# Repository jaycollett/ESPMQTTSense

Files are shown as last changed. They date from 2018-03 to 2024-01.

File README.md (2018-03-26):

# ESPMQTTSense
ESP8266 based environment sensor using the BME280 and MQTT communication. Designed to populate sensor data in my HASS.IO system. More details can be found in my blog post about this project [here](https://www.jaycollett.com/2018/03/cheap-environment-sensing-with-esp8266-mqtt).

**BOM**
----------
1. [ESP8266 ESP-01](https://www.aliexpress.com/item/WiFi-module-ESP8266-Serial-to-WiFi-wireless-transparent-transmission-industrial-ESP-01S/32716268094.html)
2. [Custom OSH Park PCBs x 3](https://oshpark.com/shared_projects/DTD2a0g7)
3. Passive Components - micro usb is part number: 10103594-0001LF
4. [Enclosure x5](https://www.ebay.com/itm/H1-5pcs-Plastic-Electric-Project-Junction-Box-60x36x25mm/282124733873)
5. [BME280 Sensor Module](https://www.banggood.com/CJMCU-280E-BME280-High-Precision-Atmospheric-Pressure-Sensor-For-Arduino-p-1103115.html)
6. [USB Wall Plug](https://www.aliexpress.com/item/Universal-USB-Charger-US-EU-Plug-5V-1A-Charger-Adapter-for-iphone-6-6s-7-7s/32822757190.html)
7. [1m USB Micro Cable](https://www.aliexpress.com/item/USB-Cable-Micro-USB-Cable-Charging-Sync-Data-Mobile-Phone-Cables-For-Android-Samsung-Xiaomi-Huawei/32852902325.html)



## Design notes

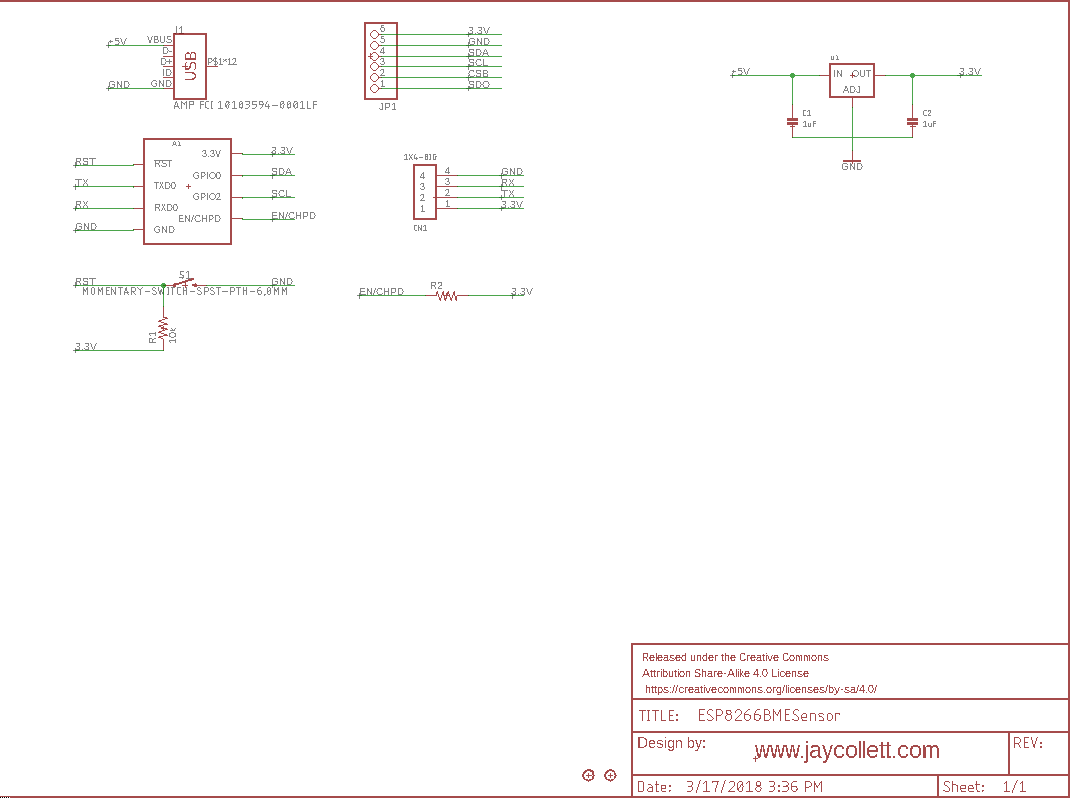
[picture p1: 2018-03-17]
EagleCAD/ESPMQTTSenseSchematic_NON_FTDI.png

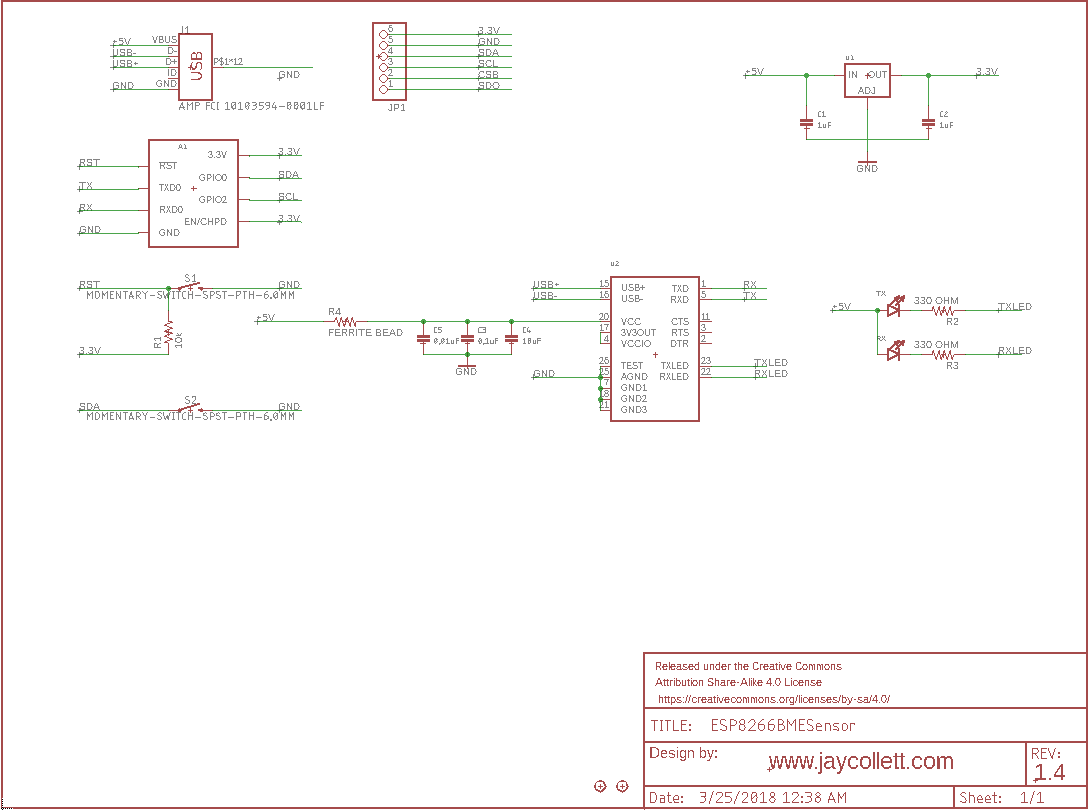
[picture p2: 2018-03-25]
EagleCAD/ESPMQTTSenseSchematic.PNG

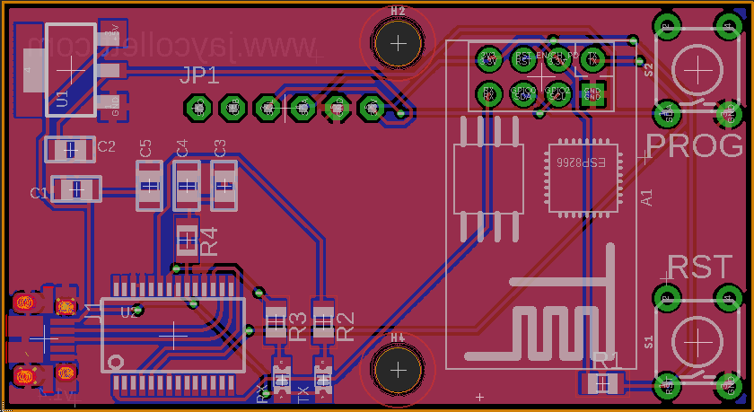
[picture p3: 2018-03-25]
EagleCAD/ESPMQTTSenseBoard.PNG

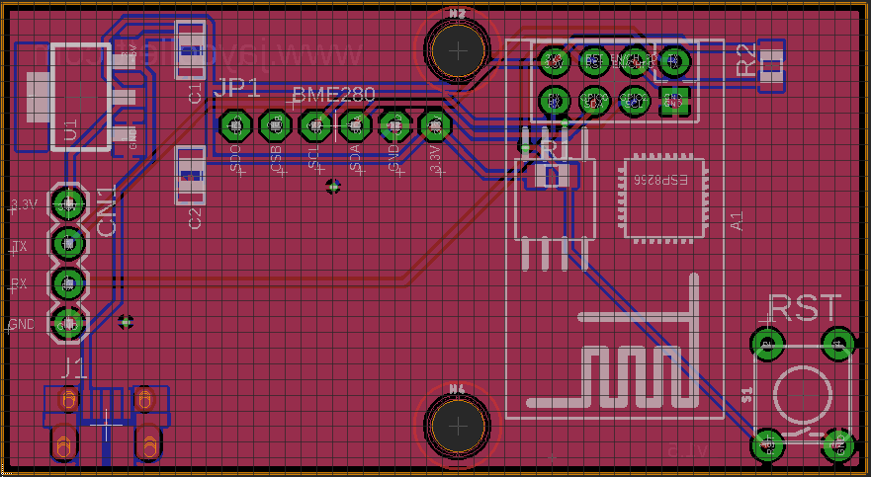
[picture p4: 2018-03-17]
EagleCAD/ESPMQTTSenseBoard_NON_FTDI.png

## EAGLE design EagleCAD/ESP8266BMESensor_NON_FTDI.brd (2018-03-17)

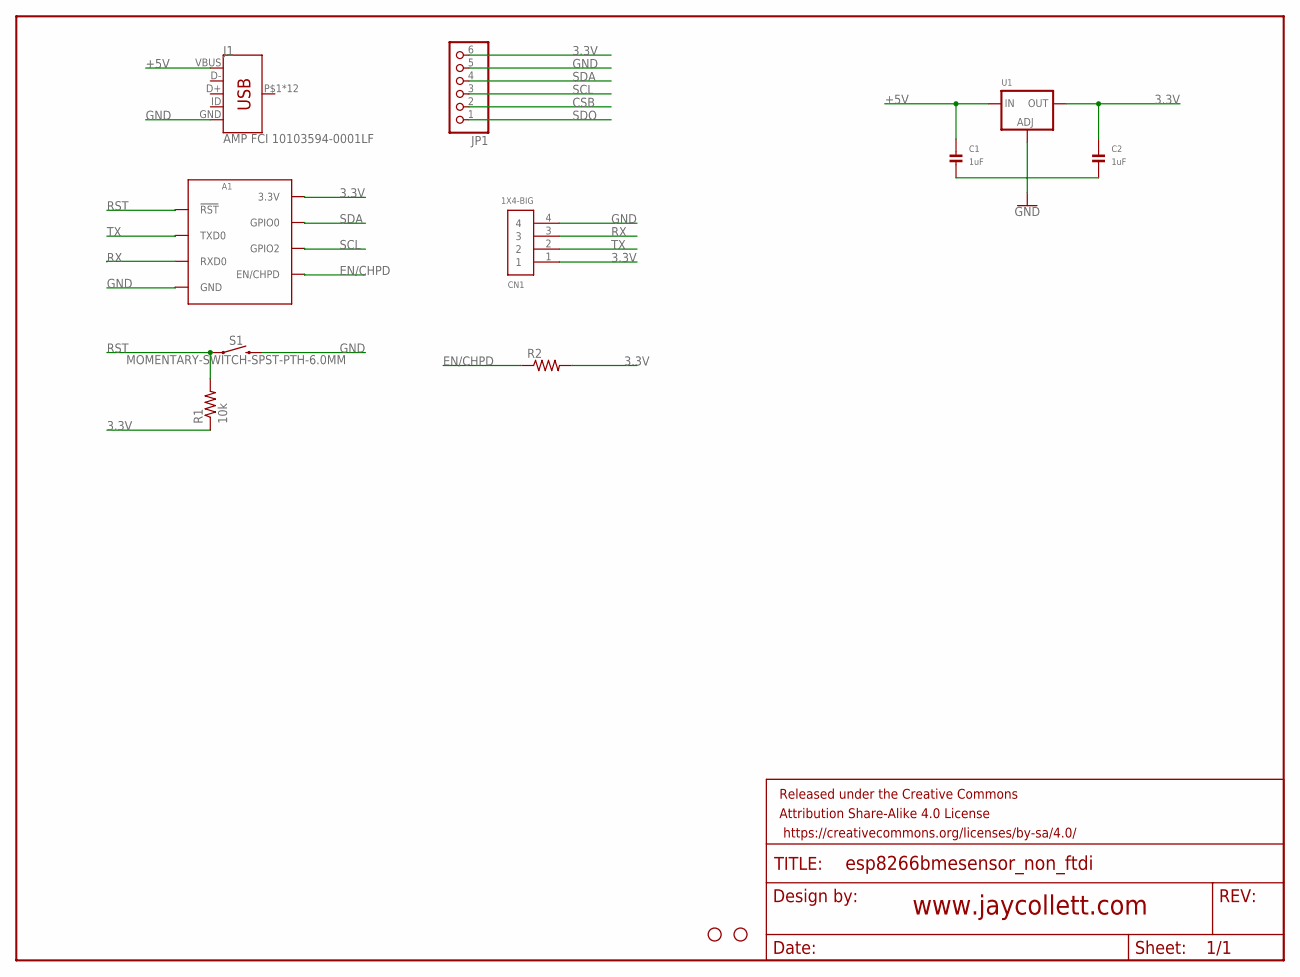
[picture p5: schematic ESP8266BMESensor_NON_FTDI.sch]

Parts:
A1: ESP8266_ESP-01; ESP8266_ESP-01_NO-SILKSCREEN
C1, C2: 1uF; 0805
CN1: 1X4-BIG; 1X04-BIG
FRAME1: FRAME-LETTERNO_PACKAGE; DUMMY
H2, H4: STAND-OFF
J1: AMP FCI 10103594-0001LF; USB-MICROB-PTH
JP1: PINHD-1X6CB; 1X06-CLEANBIG
R1: 10k; R0805
R2: R-US_R0805; R0805
S1: MOMENTARY-SWITCH-SPST-PTH-6.0MM; TACTILE_SWITCH_PTH_6.0MM
U1: LM1117SOT223-WAVE; SOT223-W

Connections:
3.3V: A1.3V3 (3.3V), C2.1, CN1.1, JP1.6, R1.1, R2.2, U1.2 (OUT)
+5V: C1.1, J1.VBUS, U1.3 (IN)
CSB: JP1.2
EN/CHPD: A1.EN/CH_PD (EN/CHPD), R2.1
GND: A1.GND, C1.2, C2.2, CN1.4, J1.GND, JP1.5, S1.3 (2), U1.1 (ADJ)
RST: A1.RST (!RST!), R1.2, S1.1
RX: A1.RX (RXD0), CN1.3
SCL: A1.GPIO2, JP1.3
SDA: A1.GPIO0, JP1.4
SDO: JP1.1
TX: A1.TX (TXD0), CN1.2

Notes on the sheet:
www.jaycollett.com

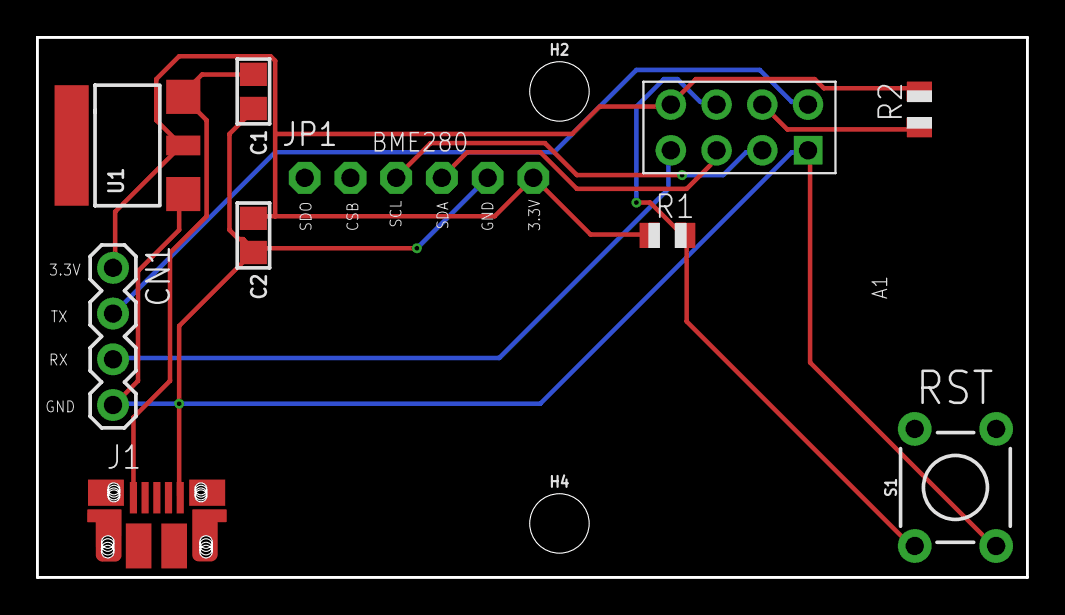
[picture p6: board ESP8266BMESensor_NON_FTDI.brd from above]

Board: 2 copper layers, 55.0 x 30.0 mm, 13 parts (0 on the bottom side), 9 nets.

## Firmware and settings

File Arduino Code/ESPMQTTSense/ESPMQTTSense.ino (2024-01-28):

#include <ESP8266WiFi.h>
#include <PubSubClient.h>
#include <Adafruit_Sensor.h>
#include <Adafruit_BME280.h>
#include <WiFiManager.h>                  //https://github.com/tzapu/WiFiManager WiFi Configuration Magic

#define MQTT_PORT 1883							      // default MQTT broker port

char  fmversion[7] = "v2.6";					    // firmware version of this sensor
char  mqtt_server[] = "192.168.0.xxxx";		// MQTT broker IP address
char  mqtt_username[] = "xxxxxxxxx";			// username for MQTT broker (USE ONE)
char  mqtt_password[] = "xxxxxxxxxxx";		// password for MQTT broker
char  mqtt_clientid[] = "remotesense4";	  // client id for connections to MQTT broker

ADC_MODE(ADC_VCC);

unsigned long previousPublishMillis = 0;  // store the last time we published data  
const long publishInterval = 300000;      // interval (in MS) to update data (5 min)
unsigned long currentMillis;              // store LOT mcu has been running
unsigned int runCount = 0;

const String baseTopic = "remotesense4";
const String tempTopic = baseTopic + "/" + "temperature";
const String humiTopic = baseTopic + "/" + "humidity";
const String presTopic = baseTopic + "/" + "pressure";
const String vccTopic  = baseTopic + "/" + "vcc";
const String fwTopic   = baseTopic + "/" + "firmwarever";

char temperature[6];
char humidity[6];
char pressure[7];
char vcc[10];

WiFiManager wifiManager;
WiFiClient wifiClient;
PubSubClient mqttclient(wifiClient);
Adafruit_BME280 bme; // I2C init

void setup() {
  Serial.begin(115200);
  delay(1000);
  Serial.println("Starting Wire");
  WiFi.mode(WIFI_STA);
    
  Wire.begin(2, 0); // GPIO2 and GPIO0 on the ESP
  Wire.setClock(100000);
  Serial.println("Searching for sensors");
  
   if (!bme.begin(0x76)) {
     Serial.println("Could not find a valid BME280 sensor, check wiring!");
     delay(3000);
     ESP.reset();
     delay(5000);
   }

  Serial.println();
  Serial.print("Connecting to WiFi...");

  // configure the wifi manager to timeout and
  wifiManager.setConfigPortalTimeout(180);
  if(!wifiManager.autoConnect()) {
      Serial.println("Failed to connect, restarting ESP...");
      delay(3000);
      ESP.reset();
      delay(5000);
  }

  mqttclient.setServer(mqtt_server, MQTT_PORT);
}

void loop() {
  
  yield(); // yield for wifi 
  
  // check to see if it's time to publish based on millis
  currentMillis = millis();
  if ( (currentMillis - previousPublishMillis >= publishInterval) || (runCount == 0) ){
    runCount = 1;
    bmeRead();
    vccRead();
    
    MQTT_connect(); // connect to wifi/mqtt as needed
    mqttclient.publish(tempTopic.c_str(), temperature);
    mqttclient.publish(humiTopic.c_str(), humidity);
    mqttclient.publish(presTopic.c_str(), pressure);
    mqttclient.publish(vccTopic.c_str(), vcc);
	  mqttclient.publish(fwTopic.c_str(), fmversion);
    
    previousPublishMillis = currentMillis;
  }
}

void bmeRead() {
  float t = (bme.readTemperature()*9/5+32-13);  // converted to F from C
  float h = bme.readHumidity();
  float p = bme.readPressure()/3389.39; // get pressure in inHg

  dtostrf(t, 5, 2, temperature); // 5 chars total, 2 decimals (BME's are really accurate)
  dtostrf(h, 5, 2, humidity);	 // 5 chars total, 2 decimals (BME's are really accurate)
  dtostrf(p, 5, 2, pressure);	 // 5 chars total, 2 decimals (BME's are really accurate)
}

void vccRead() {
  float v  = ESP.getVcc() / 1000.0;
  dtostrf(v, 5, 2, vcc); // 5 chars total, 2 decimals
}

// #############################################################################
//  mqtt Connect function
//  This function connects and reconnects as necessary to the MQTT server and
//  WiFi.
//  Should be called in the loop to ensure connectivity
// #############################################################################
void MQTT_connect() {
  int8_t ret;

  // Stop if already connected.
  if (mqttclient.connected()) {
    return;
  }

  Serial.print("Connecting to MQTT... ");

  // Loop until we're reconnected
  while (!mqttclient.connected()) {
    Serial.print("Attempting MQTT connection...");
    // Attempt to connect
    if (mqttclient.connect(mqtt_clientid, mqtt_username, mqtt_password)) {
      Serial.println("connected");
    } else {
      Serial.print("failed, rc=");
      Serial.print(mqttclient.state());
      Serial.println(" try again in 2 seconds");
      // Wait 2 seconds before retrying
      delay(2000);
    }
  }
  Serial.println("MQTT Connected!");
}

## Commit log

2018-03-01 inital commit
    [ESP8266BMESensor.brd, ESP8266BMESensor.sch]
2018-03-01 fixing directory structure for project
    [ESP8266BMESensor.brd, ESP8266BMESensor.sch]
2018-03-01 adding arduino code
2018-03-01 fixing up mqtt topics
    [ESPMQTTSense.ino]
2018-03-03 updating PCB and adding USB to UART IC
    [ESP8266BMESensor.brd, ESP8266BMESensor.sch]
2018-03-17 fixing pinout for scl sda
    [ESPMQTTSense.ino]
2018-03-17 fixinng SDA/SCL pins and setting MQTT update to 5 mins
    [ESP8266BMESensor.brd, ESP8266BMESensor.sch]
2018-03-17 adding 3d printed folders
2018-03-25 adding back the FTDI version as the primary
    [ESP8266BMESensor_NON_FTDI.brd, ESP8266BMESensor_NON_FTDI.sch]
2018-03-25 updating oshpark link for board v1.4
2018-03-26 fixing mqtt clientID parameter
    [ESPMQTTSense.ino]
2018-04-02 fixing bug with IP printing
    [ESPMQTTSense.ino]
2022-04-21 New version which includes the WiFiManager AP to ease initial and reset of WiFi
    [ESPMQTTSense.ino]

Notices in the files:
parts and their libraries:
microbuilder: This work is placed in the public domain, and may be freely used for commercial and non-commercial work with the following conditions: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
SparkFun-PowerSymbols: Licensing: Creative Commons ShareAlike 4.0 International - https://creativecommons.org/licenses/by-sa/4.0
